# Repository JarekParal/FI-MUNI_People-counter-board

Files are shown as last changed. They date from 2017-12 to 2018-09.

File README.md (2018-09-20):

# FI-MUNI_People-counter-board

[Czech documentation](./DOCUMENTATION-CZ.md)

Simple board with LED displays, decade counter, BCD to 7-segment decoder

## Simulation of circuit in Every Circuit:
- [first simulation (just one counter in circuit)](http://everycircuit.com/circuit/5534090356064256)
- [second simulation (two counters in circuit)](http://everycircuit.com/circuit/5164988449947648)

## Parts
- 4× 74LS90 - Decadic BCD counter ([datasheet](http://www.ti.com/lit/ds/symlink/sn74ls90.pdf)) - can be purchased [MyArduino.cz](https://www.myarduino.cz/logicke-obvody-74ls90-dekadicky-bcd-citac) or [Farnell.com](http://cz.farnell.com/texas-instruments/sn74ls90n/ic-counter-multiplier-divider/dp/1470790?st=74ls90)
- 4× 74LS47 - Decoder BCD/7segm. ([datasheet](http://www.ti.com/lit/ds/symlink/sn74ls47.pdf)) - can be purchased [MyArduino.cz](https://www.myarduino.cz/logicke-obvody-74ls47-dekoder-z-bcd-na-7-segmentovy-kod-s-otevrenym-kolektorem) or [Farnell.com](http://cz.farnell.com/texas-instruments/sn74ls90n/ic-counter-multiplier-divider/dp/1470790?st=74ls90)
- 4× 7 seg. display HD-A554RD ([datasheet](https://www.gme.cz/data/attachments/dsh.512-182.1.pdf)) - can be purchased [GME](https://www.gme.cz/led-display-14-2mm-red-hd-a554rd)
- 31× resistor 220 Ω v package SMD0603
- 1× resistor 10 kΩ v package SMD0603
- 2×2 a 2×4 90 degree pinheads 2,54 mm
- 1× MicroUSB connector - can be purchased [Mouser](https://cz.mouser.com/ProductDetail/Molex/47346-0001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) or Farnell

## Parameters
- power supply: 5 V over pinheads or microUSB connector
- consumption: approx. 200 mA 
- size of PCB: 70 × 69 mm

## Versions of PCB - bugs and modification
### v1.0
- wrong value of the capacitor C2 near IC 555: 10 uF -> 200 nF
- wrong net to the potentiometer R29 -> delete this net in v1.1 or modify the R29 (cut off one pin on R29)
### v1.1
- fix bugs from v1.0

## Photos 

PCB with all parts
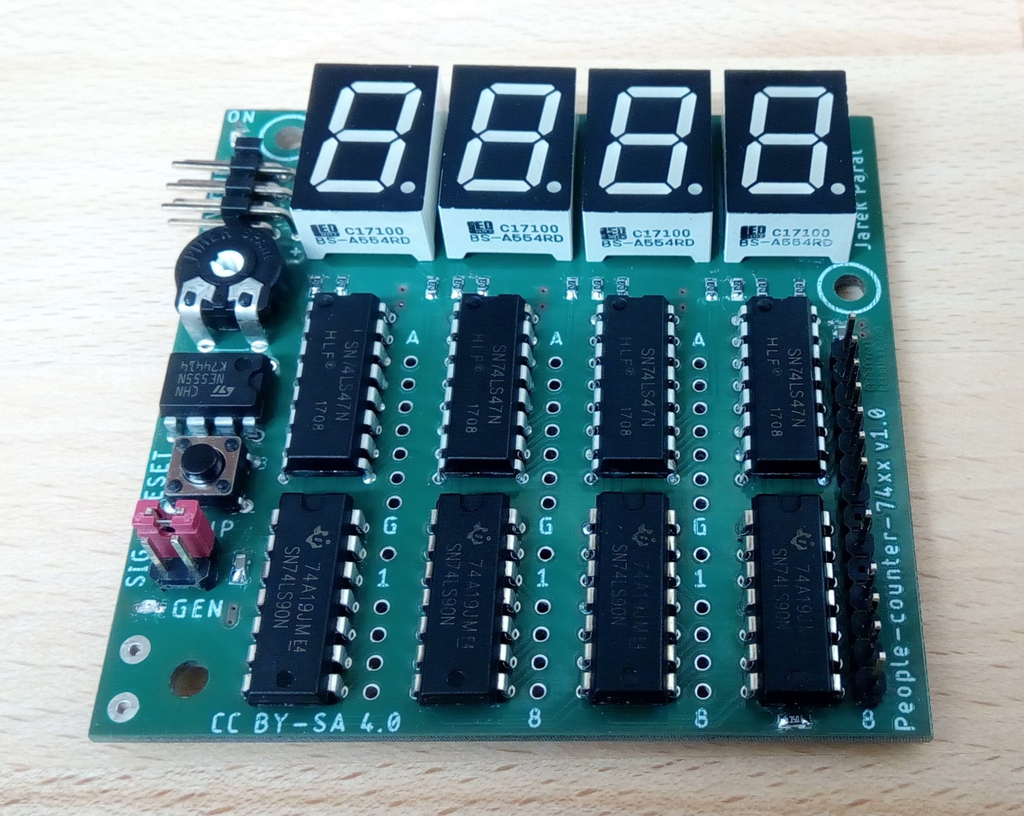
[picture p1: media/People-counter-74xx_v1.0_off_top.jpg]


PCB in operation
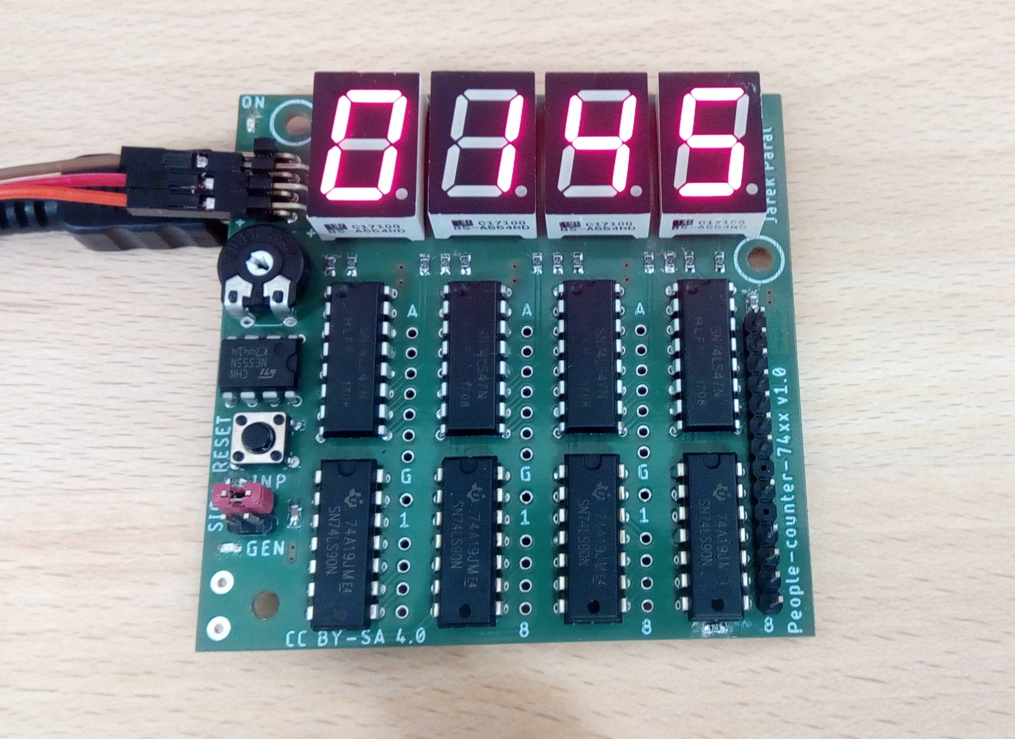
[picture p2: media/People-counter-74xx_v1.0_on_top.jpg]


PCB with USB power supply and PIR sensor
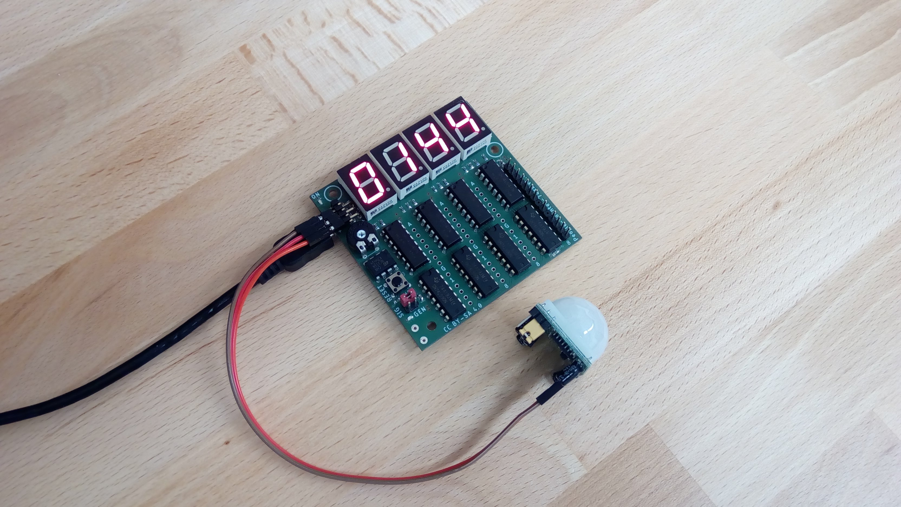
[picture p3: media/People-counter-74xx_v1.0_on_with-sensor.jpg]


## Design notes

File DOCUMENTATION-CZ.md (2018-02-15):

# Počítadlo průchodů lidí pomocí logických obvodů (People-counter-74xx)

Cílem této práce bylo navrhnout obvod, který by umožnil počítat signály generované PIR čidlem a následně zobrazovat stav na LED displejích. Výsledkem je čtyřmístný čítač postavený na obvodech 74xx.

Deska by měla také sloužit jako jednoduchý výukový kit pro předvedení využívání více kanálů na digitálním osciloskopu a trigrování vstupního signálu.    
Pro jednodušší předvádění na osciloskopu byl na DPS přidán generátor signálů postavený na čipu 555.

## Hlavní součástky

- 4× 74LS90 - Dekadický BCD čítač ([datasheet](http://www.ti.com/lit/ds/symlink/sn74ls90.pdf)) - lze koupit na [MyArduino.cz](https://www.myarduino.cz/logicke-obvody-74ls90-dekadicky-bcd-citac) nebo [Farnell.com](http://cz.farnell.com/texas-instruments/sn74ls90n/ic-counter-multiplier-divider/dp/1470790?st=74ls90)
- 4× 74LS47 - Dekodér BCD/7segm. ([datasheet](http://www.ti.com/lit/ds/symlink/sn74ls47.pdf)) - lze koupit na [MyArduino.cz](https://www.myarduino.cz/logicke-obvody-74ls47-dekoder-z-bcd-na-7-segmentovy-kod-s-otevrenym-kolektorem) nebo [Farnell.com](http://cz.farnell.com/texas-instruments/sn74ls90n/ic-counter-multiplier-divider/dp/1470790?st=74ls90)
- 4× 7 seg. displej HD-A554RD ([datasheet](https://www.gme.cz/data/attachments/dsh.512-182.1.pdf)) - lze koupit v [GME](https://www.gme.cz/led-display-14-2mm-red-hd-a554rd)
- 31× rezistor 220 Ω v pouzdře SMD0603
- 1× rezistor 10 kΩ v pouzdře SMD0603
- 2×2 a 2×4 zahnutý pinhead s roztečí 2,54 mm
- 1× MicroUSB konektor - lze zakoupit v [Mouseru](https://cz.mouser.com/ProductDetail/Molex/47346-0001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) nebo Farnellu

## Parametry
- napájení: 5 V přes pinheady nebo microUSB konektor
- odběr: cca. 200 mA 
- velikost DPS: 70 × 69 mm

## Senzor

Jako senzor pro snímání průchodu lidí jsem použil běžně dostupný [PIR sensor pohybu  HC-SR501](https://www.myarduino.cz/ir-senzorovy-modul-pohybu-hc-sr501). Nejedná se asi o nejvhodnější řešení, protože PIR čidlo je určené pro spínání osvětlení a má tak velký úhel snímání a dlouhé prodlevy mezi měřením jednotlivých průchodů (cca. 3-5 vteřin). 

Jako alternativu by šlo použít například optickou závoru složenou z LED/laseru a fototranzistoru. Toto řešení by ovšem vyžadovalo mít na jedné straně průchodu vysílač a na druhé přijímač, což by komplikovalo využívání.

## Simulace obvodu

Před samotným návrhem DPS jsem provedl základní simulace zapojení pomocí webového simulátoru [EveryCircuit](http://everycircuit.com).

Simulaci čítače od 0 do 100 si lze prohlídnout zde: https://goo.gl/AVsj5z

Zároveň jsem si jeden segment zkusil poskládat na nepájivém poli.

## Návrh obvodu

Nejprve jsem chtěl obvod navrhnout v open-source programu [KiCad](http://kicad-pcb.org/). V něm jsem vytvořil celé schéma a začal i routovat DPS. Při routování jsem byl ale krajně nespokojen s editorem plošných spojů a propojení schémtu s návrhem DPS. Proto jsem se rozhodl projekt převést do programu [Eagle](https://www.autodesk.com/products/eagle/overview).

Celý projekt jsem následně dokončil v programu Eagle.

## Schéma DPS:
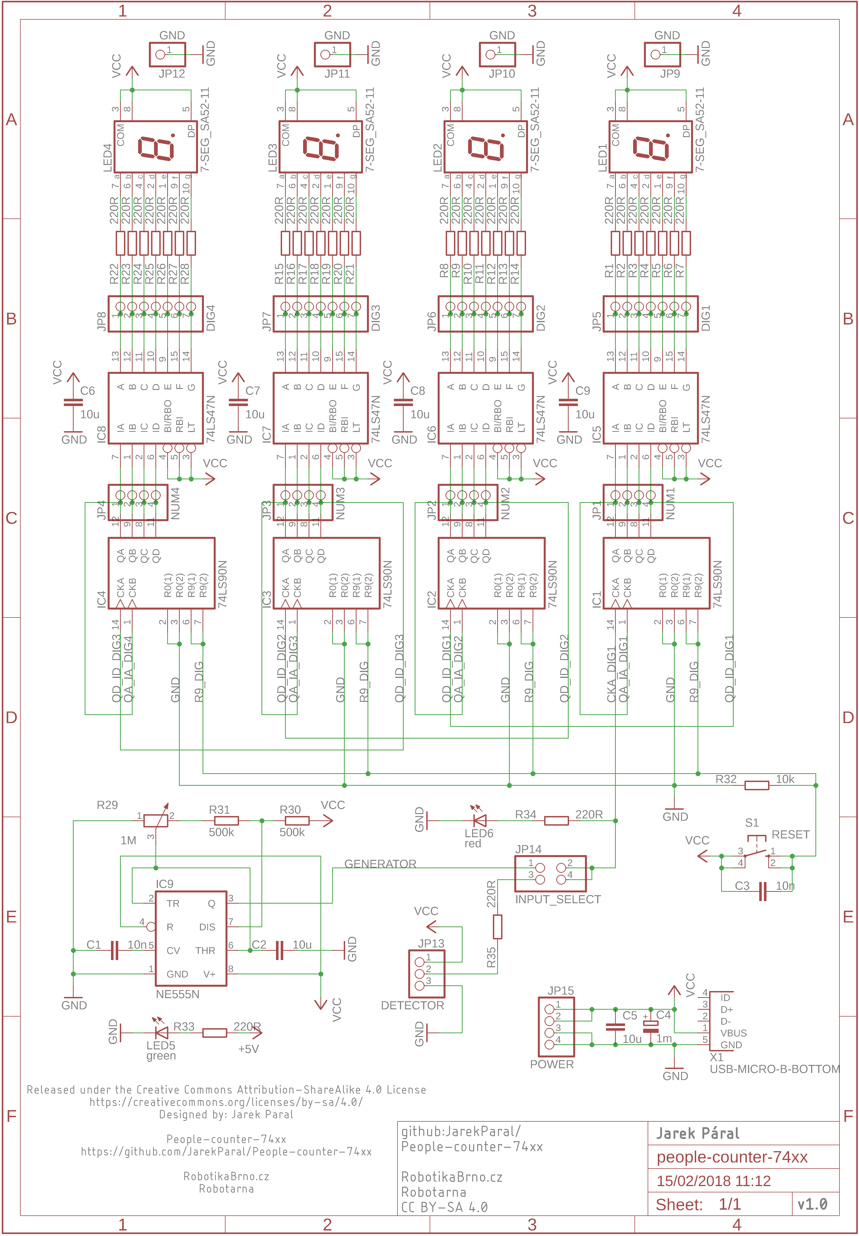
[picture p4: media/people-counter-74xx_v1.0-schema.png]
Schéma DPS People-counter-74xx


## DPS
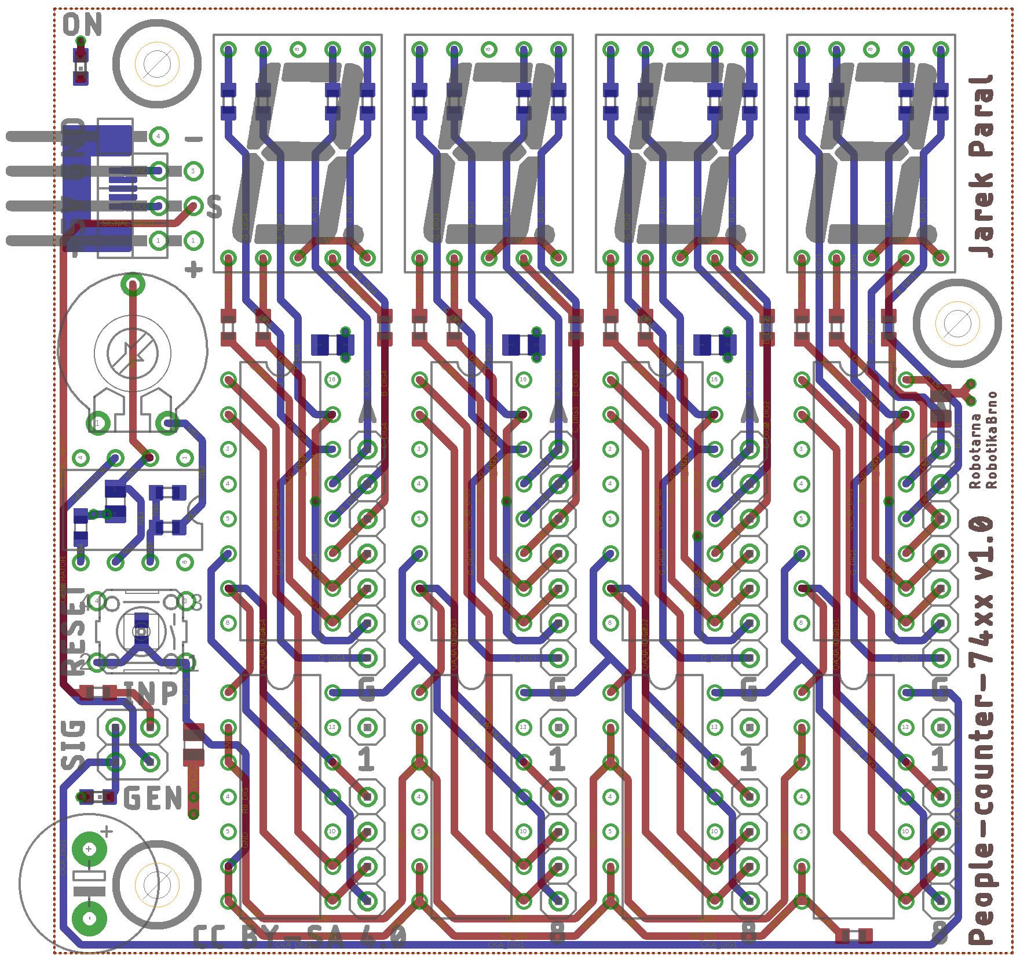
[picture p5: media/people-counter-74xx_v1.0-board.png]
DPS People-counter-74xx


## Osazování a uživování

Při osazování jsem na DPS nenalezl žádný problém. Jen mi prvně bohužel dodali špatné LED displeje (se společnou katodou místo anodou), ale naštěstí jsem to zjistil při osazování prvního displeje, a tak jsem musel odpájet jen jeden.

Při oživování celé DPS jsem si uvědomil, že mi na napájecím pinheadu chybí ochranná dioda proti přepólování. Zapracuji do další verze. Zároveň se mi stále nepodařilo uvést do chodu signálový generátor, ačkoliv by měl být zapojen dle [datasheetu](http://www.ti.com/lit/ds/symlink/ne555.pdf). Musím si zapojení ještě projít a asi vyzkoušet v nepájivém poli.

## Závěr

Výsledná DPS pro hlavní účel počítání průchodu lidí funguje bez problémů (viz [video](https://youtu.be/IY-zGMGUtn4)). Generátor signálů se mi zatím nepodařilo zprovoznit, ale doufám, že by to mohlo být například jen špatně zvolenými hodnotami součástek.

Pro účely výuky práce s osciloskopem lze DPS již částečně využít i bez generátoru signálů, ať už s nastavenou dlouhou časovou základnou anebo za pomoci generování signálů z externího zdroje.

## Fotogalerie 

Kompletně osazená DPS


Zapnutá DPS


DPS s připojeným USB napájením a PIR senzorem


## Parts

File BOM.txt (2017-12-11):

GES - LED displeje
https://www.ges.cz/cz/elektronicke-soucastky/led-diody-optosoucastky-pristrojove-zarovky/led-displeje/SADI.html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

GME - LED displeje
https://www.gme.cz/led-displeje?page=1#products

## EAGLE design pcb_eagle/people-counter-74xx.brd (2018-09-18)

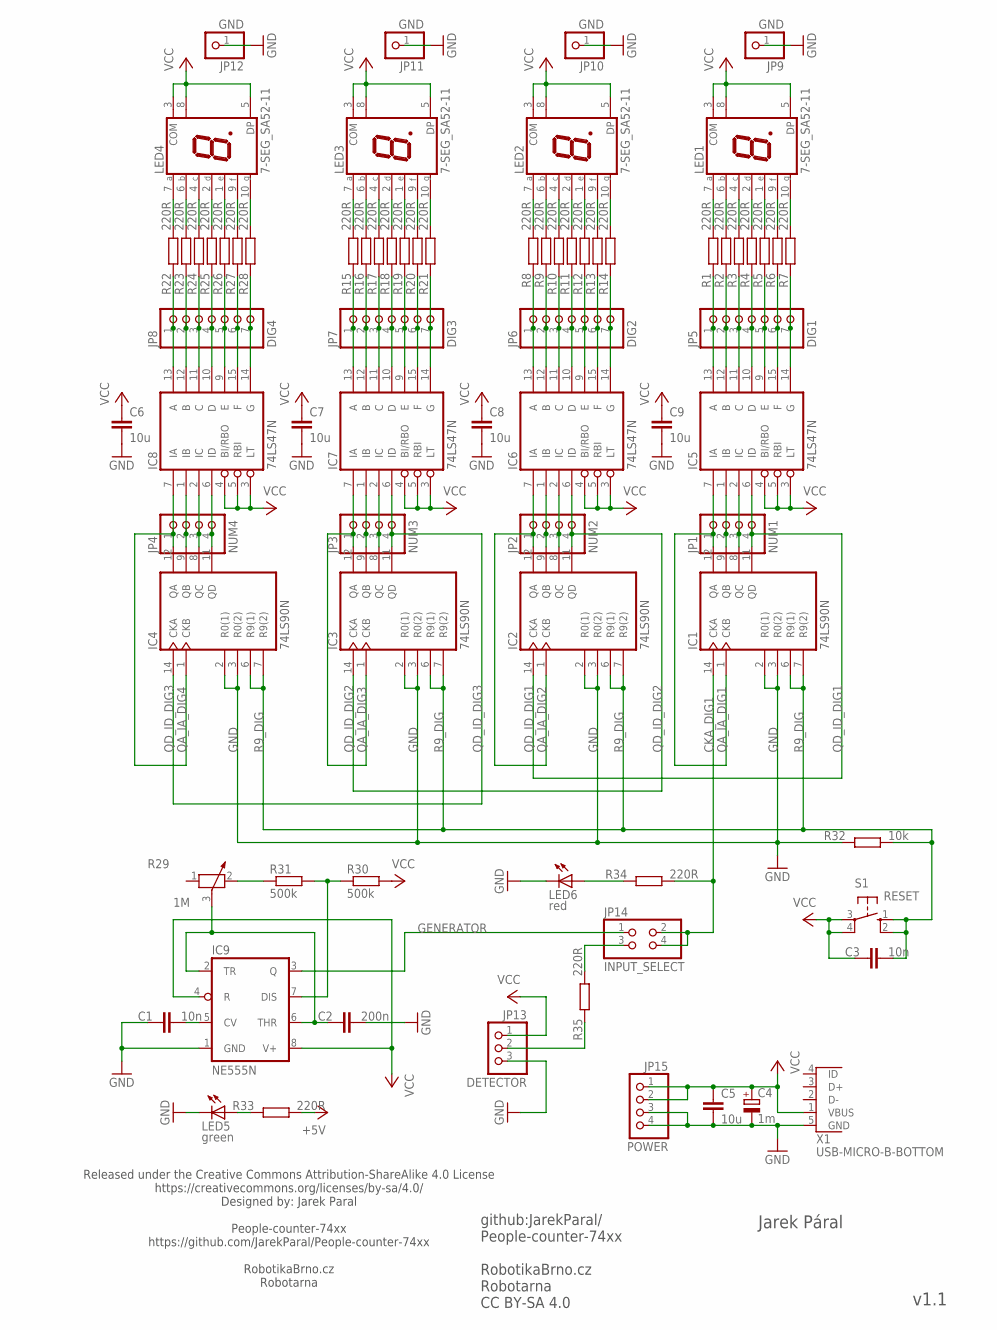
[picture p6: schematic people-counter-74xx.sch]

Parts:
C1, C3: 10n; C0603
C2: 200n; C0805
C4: 1m; E5-10,5
C5, C6, C7, C8, C9: 10u; C0805
IC1, IC2, IC3, IC4: 74LS90N; DIL14
IC5, IC6, IC7, IC8: 74LS47N; DIL16
IC9: NE555N; DIL08
JP1: NUM1; 1X04
JP2: NUM2; 1X04
JP3: NUM3; 1X04
JP4: NUM4; 1X04
JP5: DIG1; 1X07
JP6: DIG2; 1X07
JP7: DIG3; 1X07
JP8: DIG4; 1X07
JP9, JP10, JP11, JP12: GND; 1X01
JP13: DETECTOR; 1X03/90
JP14: INPUT_SELECT; 2X02
JP15: POWER; 1X04/90
LED1, LED2, LED3, LED4: 7-SEG_SA52-11; SA52-11
LED5: green; CHIPLED_0603
LED6: red; CHIPLED_0603
R1, R2, R3, R4, R5, R6, R7, R8, R9, R10, R11, R12, R13, R14, R15, R16, R17, R18, R19, R20, R21, R22, R23, R24, R25, R26, R27, R28, R33, R34, R35: 220R; R0603
R29: 1M; PT-10
R30, R31: 500k; R0603
R32: 10k; R0603
S1: RESET; B3F-10XX
X1: USB-MICRO-B-BOTTOM; USB-MICRO-B-BOTTOM-MOLEX

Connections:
+5V: R33.2
A_DIG1: IC5.13 (A), JP5.1, R1.1
A_DIG2: IC6.13 (A), JP6.1, R8.1
A_DIG3: IC7.13 (A), JP7.1, R15.1
A_DIG4: IC8.13 (A), JP8.1, R22.1
A_DIG_1: LED1.7 (A), R1.2
A_DIG_2: LED2.7 (A), R8.2
A_DIG_3: LED3.7 (A), R15.2
A_DIG_4: LED4.7 (A), R22.2
B_DIG1: IC5.12 (B), JP5.2, R2.1
B_DIG2: IC6.12 (B), JP6.2, R9.1
B_DIG3: IC7.12 (B), JP7.2, R16.1
B_DIG4: IC8.12 (B), JP8.2, R23.1
B_DIG_1: LED1.6 (B), R2.2
B_DIG_2: LED2.6 (B), R9.2
B_DIG_3: LED3.6 (B), R16.2
B_DIG_4: LED4.6 (B), R23.2
CKA_DIG1: IC1.14 (CKA), JP14.2, JP14.4, R34.2
C_DIG1: IC5.11 (C), JP5.3, R3.1
C_DIG2: IC6.11 (C), JP6.3, R10.1
C_DIG3: IC7.11 (C), JP7.3, R17.1
C_DIG4: IC8.11 (C), JP8.3, R24.1
C_DIG_1: LED1.4 (C), R3.2
C_DIG_2: LED2.4 (C), R10.2
C_DIG_3: LED3.4 (C), R17.2
C_DIG_4: LED4.4 (C), R24.2
D_DIG1: IC5.10 (D), JP5.4, R4.1
D_DIG2: IC6.10 (D), JP6.4, R11.1
D_DIG3: IC7.10 (D), JP7.4, R18.1
D_DIG4: IC8.10 (D), JP8.4, R25.1
D_DIG_1: LED1.2 (D), R4.2
D_DIG_2: LED2.2 (D), R11.2
D_DIG_3: LED3.2 (D), R18.2
D_DIG_4: LED4.2 (D), R25.2
E_DIG1: IC5.9 (E), JP5.5, R5.1
E_DIG2: IC6.9 (E), JP6.5, R12.1
E_DIG3: IC7.9 (E), JP7.5, R19.1
E_DIG4: IC8.9 (E), JP8.5, R26.1
E_DIG_1: LED1.1 (E), R5.2
E_DIG_2: LED2.1 (E), R12.2
E_DIG_3: LED3.1 (E), R19.2
E_DIG_4: LED4.1 (E), R26.2
F_DIG1: IC5.15 (F), JP5.6, R6.1
F_DIG2: IC6.15 (F), JP6.6, R13.1
F_DIG3: IC7.15 (F), JP7.6, R20.1
F_DIG4: IC8.15 (F), JP8.6, R27.1
F_DIG_1: LED1.9 (F), R6.2
F_DIG_2: LED2.9 (F), R13.2
F_DIG_3: LED3.9 (F), R20.2
F_DIG_4: LED4.9 (F), R27.2
GENERATOR: IC9.3 (Q), JP14.1
GND: C1.1, C2.2, C4.-, C5.2, C6.2, C7.2, C8.2, C9.2, IC1.2 (R0(1)), IC1.3 (R0(2)), IC1.10 (GND), IC2.2 (R0(1)), IC2.3 (R0(2)), IC2.10 (GND), IC3.2 (R0(1)), IC3.3 (R0(2)), IC3.10 (GND), IC4.2 (R0(1)), IC4.3 (R0(2)), IC4.10 (GND), IC5.8 (GND), IC6.8 (GND), IC7.8 (GND), IC8.8 (GND), IC9.1 (GND), JP9.1, JP10.1, JP11.1, JP12.1, JP13.3, JP15.3, JP15.4, LED5.C, LED6.C, R32.1, X1.5 (GND)
G_DIG1: IC5.14 (G), JP5.7, R7.1
G_DIG2: IC6.14 (G), JP6.7, R14.1
G_DIG3: IC7.14 (G), JP7.7, R21.1
G_DIG4: IC8.14 (G), JP8.7, R28.1
G_DIG_1: LED1.10 (G), R7.2
G_DIG_2: LED2.10 (G), R14.2
G_DIG_3: LED3.10 (G), R21.2
G_DIG_4: LED4.10 (G), R28.2
unnamed: LED6.A, R34.1
unnamed: R29.2, R31.1
unnamed: C2.1, IC9.2 (TR), IC9.6 (THR), R29.3
unnamed: C1.2, IC9.5 (CV)
unnamed: IC9.7 (DIS), R30.1, R31.2
unnamed: LED5.A, R33.1
QA_IA_DIG1: IC1.1 (CKB), IC1.12 (QA), IC5.7 (IA), JP1.1
QA_IA_DIG2: IC2.1 (CKB), IC2.12 (QA), IC6.7 (IA), JP2.1
QA_IA_DIG3: IC3.1 (CKB), IC3.12 (QA), IC7.7 (IA), JP3.1
QA_IA_DIG4: IC4.1 (CKB), IC4.12 (QA), IC8.7 (IA), JP4.1
QB_IB_DIG1: IC1.9 (QB), IC5.1 (IB), JP1.2
QB_IB_DIG2: IC2.9 (QB), IC6.1 (IB), JP2.2
QB_IB_DIG3: IC3.9 (QB), IC7.1 (IB), JP3.2
QB_IB_DIG4: IC4.9 (QB), IC8.1 (IB), JP4.2
QC_IC_DIG1: IC1.8 (QC), IC5.2 (IC), JP1.3
QC_IC_DIG2: IC2.8 (QC), IC6.2 (IC), JP2.3
QC_IC_DIG3: IC3.8 (QC), IC7.2 (IC), JP3.3
QC_IC_DIG4: IC4.8 (QC), IC8.2 (IC), JP4.3
QD_ID_DIG1: IC1.11 (QD), IC2.14 (CKA), IC5.6 (ID), JP1.4
QD_ID_DIG2: IC2.11 (QD), IC3.14 (CKA), IC6.6 (ID), JP2.4
QD_ID_DIG3: IC3.11 (QD), IC4.14 (CKA), IC7.6 (ID), JP3.4
QD_ID_DIG4: IC4.11 (QD), IC8.6 (ID), JP4.4
R9_DIG: C3.2, IC1.6 (R9(1)), IC1.7 (R9(2)), IC2.6 (R9(1)), IC2.7 (R9(2)), IC3.6 (R9(1)), IC3.7 (R9(2)), IC4.6 (R9(1)), IC4.7 (R9(2)), R32.2, S1.1 (S), S1.2 (S1)
SIGNAL_INPUT: JP13.2, R35.1
SIGNAL_INPUT_: JP14.3, R35.2
VCC: C3.1, C4.+, C5.1, C6.1, C7.1, C8.1, C9.1, IC1.5 (VCC), IC2.5 (VCC), IC3.5 (VCC), IC4.5 (VCC), IC5.3 (LT), IC5.4 (BI/RBO), IC5.5 (RBI), IC5.16 (VCC), IC6.3 (LT), IC6.4 (BI/RBO), IC6.5 (RBI), IC6.16 (VCC), IC7.3 (LT), IC7.4 (BI/RBO), IC7.5 (RBI), IC7.16 (VCC), IC8.3 (LT), IC8.4 (BI/RBO), IC8.5 (RBI), IC8.16 (VCC), IC9.4 (R), IC9.8 (V+), JP13.1, JP15.1, JP15.2, LED1.3 (COM), LED1.5 (DP), LED1.8 (COM), LED2.3 (COM), LED2.5 (DP), LED2.8 (COM), LED3.3 (COM), LED3.5 (DP), LED3.8 (COM), LED4.3 (COM), LED4.5 (DP), LED4.8 (COM), R30.2, S1.3, S1.4 (P1), X1.1 (VBUS)

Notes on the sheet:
github:JarekParal/ People-counter-74xx RobotikaBrno.cz Robotarna CC BY-SA 4.0
Jarek Páral
v1.1
Released under the Creative Commons Attribution-ShareAlike 4.0 License https://creativecommons.org/licenses/by-sa/4.0/ Designed by: Jarek Paral People-counter-74xx https://github.com/JarekParal/People-counter-74xx RobotikaBrno.cz Robotarna

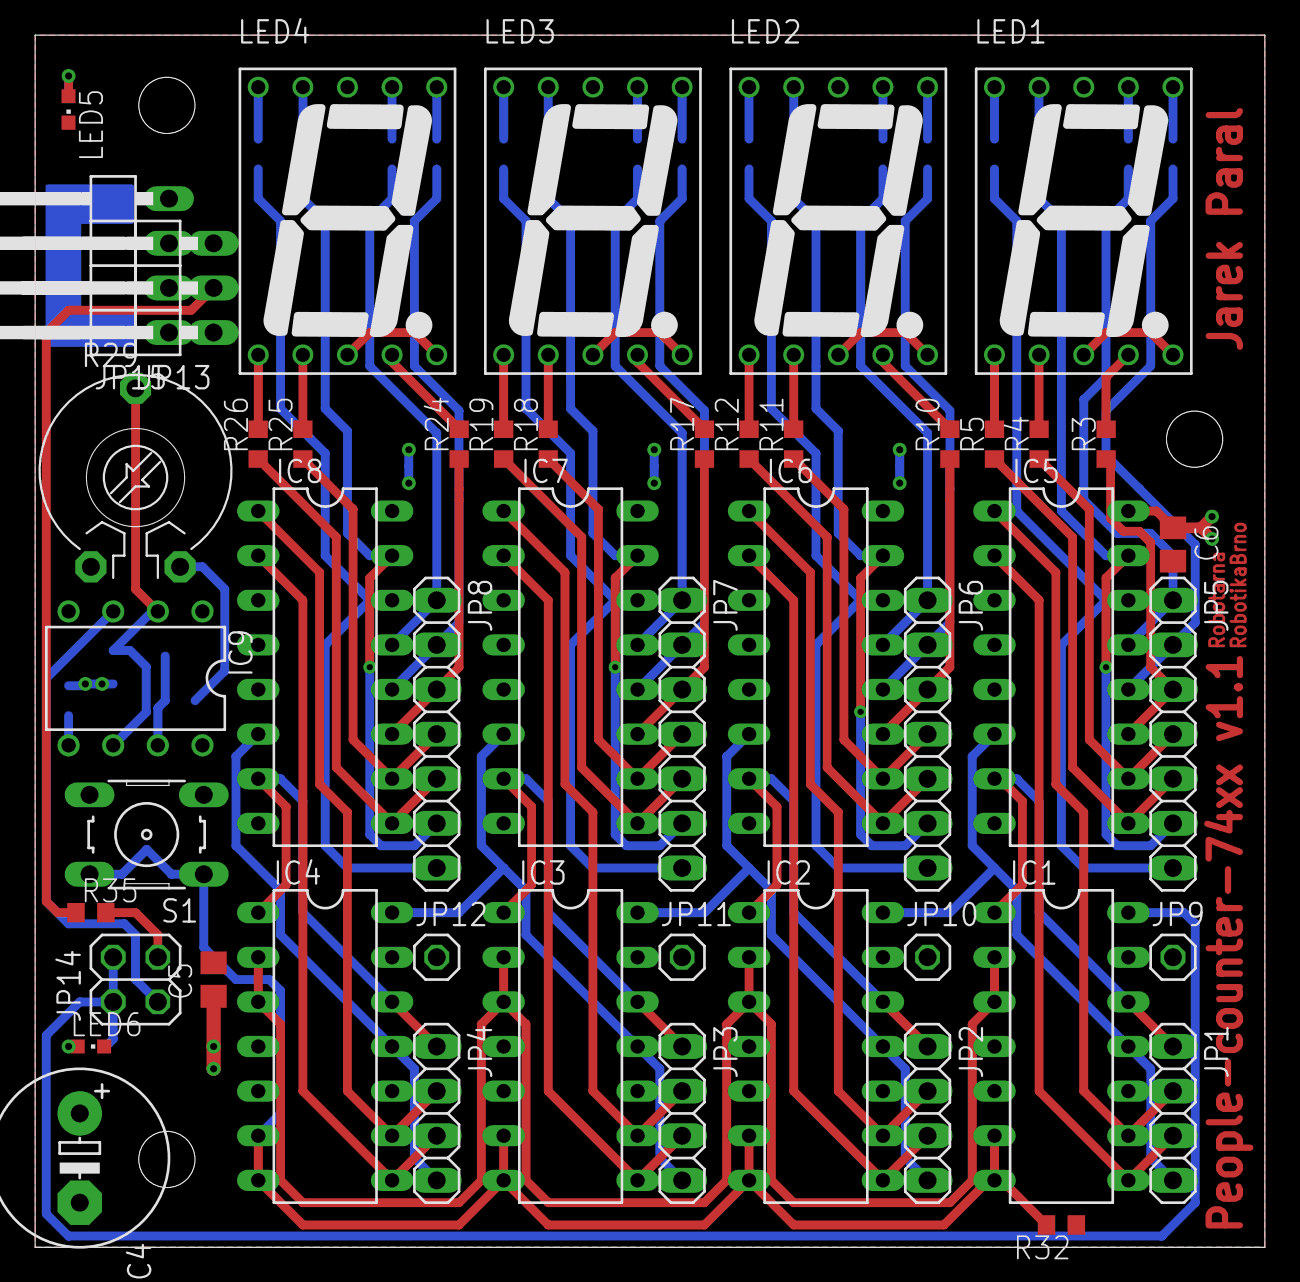
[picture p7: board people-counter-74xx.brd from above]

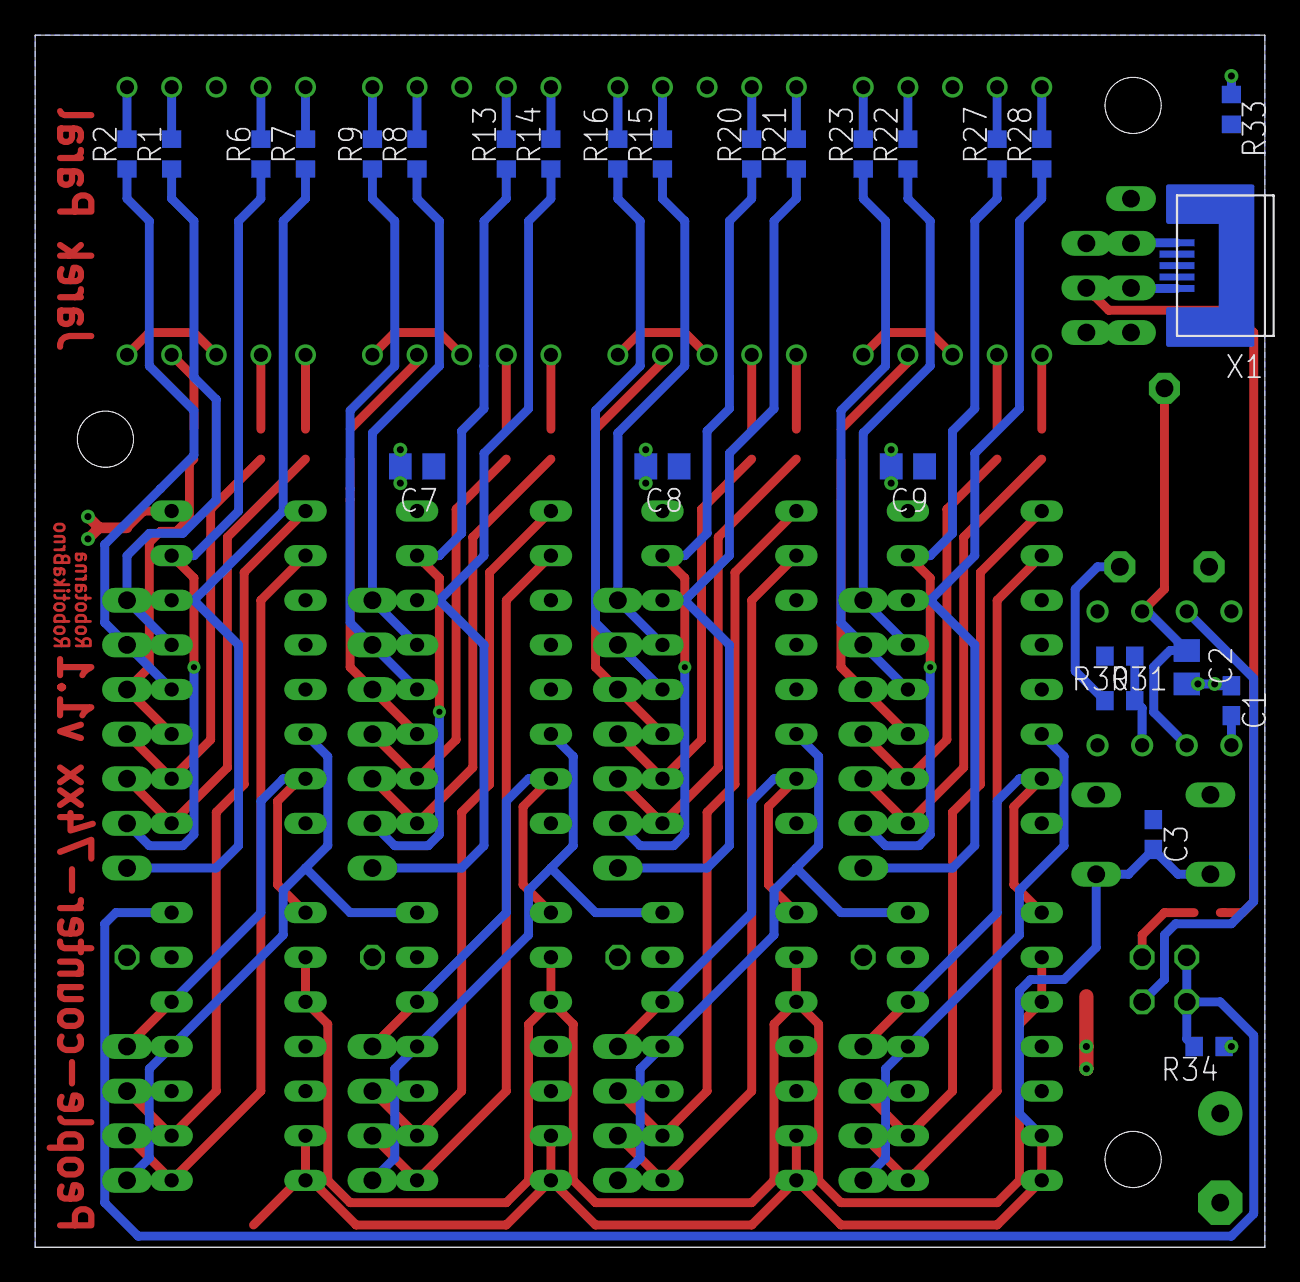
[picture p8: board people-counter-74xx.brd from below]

Board: 2 copper layers, 70.0 x 69.0 mm, 76 parts (27 on the bottom side), 85 nets.

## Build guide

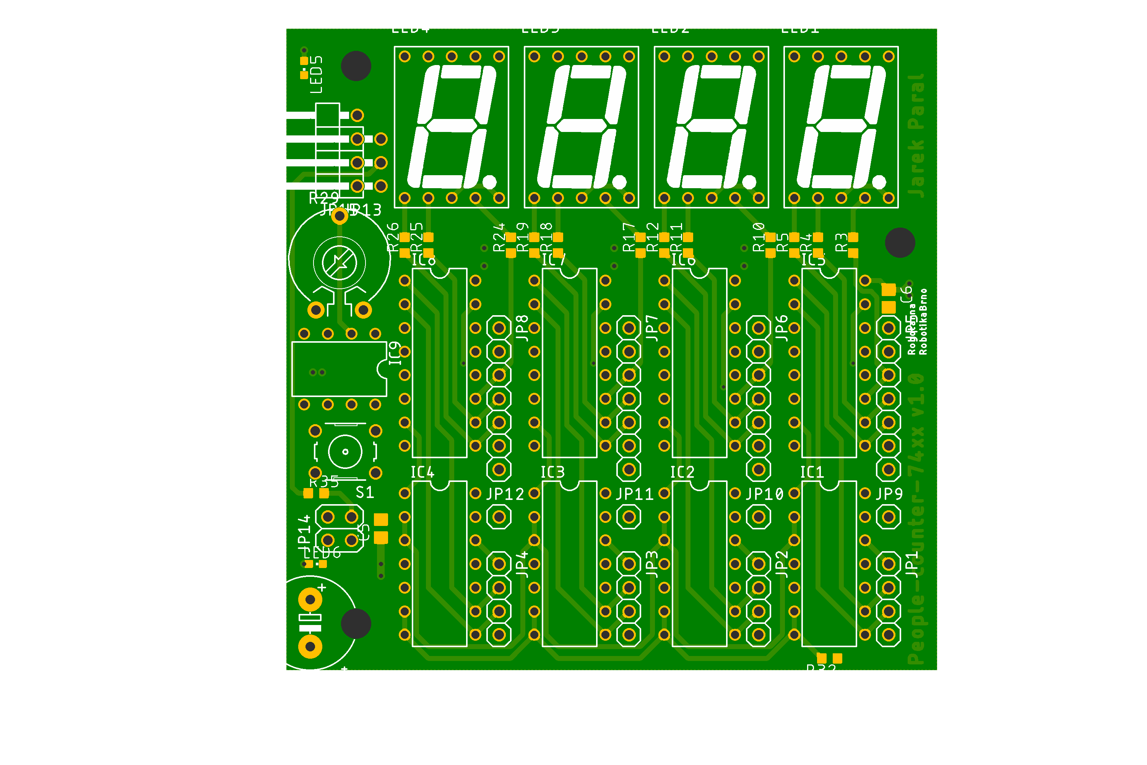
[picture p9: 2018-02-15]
media/people-counter-74xx_v1.0-manufacturing.png

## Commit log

2017-12-11 Schema: first version
    [people-counter-74xx.kicad_pcb, people-counter-74xx.sch]
2017-12-11 Update README and add BOM
2017-12-14 Schema: improves - remove excessive AND2 gate, add SW to reset counter IC
    [people-counter-74xx.kicad_pcb, people-counter-74xx.sch]
2018-01-29 Schema: final version of schema
    [people-counter-74xx.sch]
2018-01-29 PCB: add footprint of part HD-A552RD
2018-01-29 PCB: rename folder "pcb" to "pcb_kicad"
    [people-counter-74xx.kicad_pcb, people-counter-74xx.sch]
2018-01-29 PCB_EAGLE: add first version of schema and layout of board with one LED segment (= design block)
    [people-counter-74xx.brd, people-counter-74xx.sch]
2018-01-29 PCB_EAGLE: add design module - LED segment counter
2018-01-29 PCB_EAGLE: finish layout of 4 design module (LED segment counter}
    [people-counter-74xx.brd, people-counter-74xx.sch]
2018-01-29 PCB_EAGLE: improve nets in design block LED segment counter
2018-01-30 PCB_EAGLE: add frequency square wave generator based on the NE555 and some connectors to schema
    [people-counter-74xx.brd, people-counter-74xx.sch]
2018-01-31 PCB_EAGLE: final layout of board
    [people-counter-74xx.brd, people-counter-74xx.sch]
2018-02-02 PCB_EAGLE: add a few description text and some optimization of net
    [people-counter-74xx.brd, people-counter-74xx.sch]
2018-02-14 PCB_EAGLE: start work on version 1.1 - repair layer of texts Robotarna RobotikaBrno
    [people-counter-74xx.brd, people-counter-74xx.sch]
2018-09-18 PCB_EAGLE: fix two bugs from v1.0 - change value of C2 (10u -> 200n) - delete one wire on potentiometer (R29)
    [people-counter-74xx.brd, people-counter-74xx.sch]
